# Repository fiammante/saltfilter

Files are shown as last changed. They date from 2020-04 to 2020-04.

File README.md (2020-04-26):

# saltfilter
OpenScad filter for full face snorkeling mask.

Making my full-face protection mask from a snorkel mask. 
Given the lack of masks, after reading [“Universal and reusable virus deactivation system for respiratory protection” article on nature](https://www.nature.com/articles/srep39956) and [“A biomedical engineer created a mask coated in salt that he says could neutralize viruses like the coronavirus in 5 minutes” on business insider](https://www.businessinsider.fr/us/mask-coated-in-salt-neutralizes-viruses-like-coronavirus-2020-2) , then seeing [“European researchers retrofit snorkel masks for coronavirus fight” on Reuters](https://www.reuters.com/article/us-health-coronavirus-czech-snorkel-mask-idUSKBN21H2Z5) I decided to build reusable masks for me and my wife, better than nothing.
I bought a full face mask on amazon and replaced the snorkel by a 3d printed salt filter designed with Openscad https://www.openscad.org/.
This project contains the OpenScad parts for this [masks I bought on Amazon](https://www.amazon.fr/gp/product/B07L8RH96N/ref=ppx_yo_dt_b_asin_title_o04_s00?ie=UTF8&psc=1) 
If you have another mask the inletv.scad out outletv.scad should be changed to fit yours.

The parts to print are filter.scad for the filter itself and grid.scad for the 4 grid separation that maintain the high granularity salt in place.

# Making my full-face protection mask from a snorkel mask.

Given the lack of masks, after reading [&quot;Universal and reusable virus deactivation system for respiratory protection&quot;](https://www.nature.com/articles/srep39956) article on nature and [&quot;A biomedical engineer created a mask coated in salt that he says could neutralize viruses like the coronavirus in 5 minutes&quot;](https://www.businessinsider.fr/us/mask-coated-in-salt-neutralizes-viruses-like-coronavirus-2020-2) on business insider, then seeing [&quot;European researchers retrofit snorkel masks for coronavirus fight&quot;](https://www.reuters.com/article/us-health-coronavirus-czech-snorkel-mask-idUSKBN21H2Z5) on Reuters I decided to build reusable masks for me and my wife, better than nothing.

Here are the steps that I followed

I bought the following &quot;Speedsporting Full Face Snorkel Mask 180°&quot; on Amazon: 

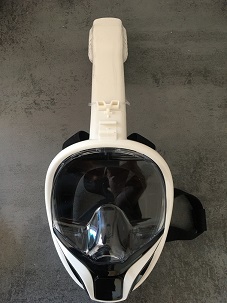
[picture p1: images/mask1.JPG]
Mask1
 

2/ Remove the snorkel one pin to remove) 

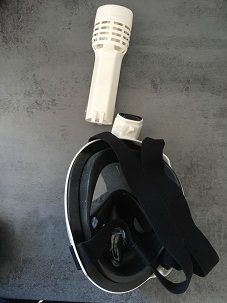
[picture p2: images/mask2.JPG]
Mask2


3/ View from top Air in and out flows. These snorkel masks separate with valves the air flow going in and going out. |

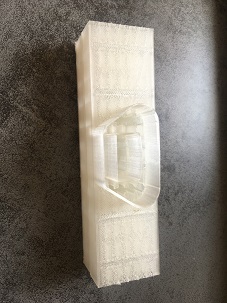
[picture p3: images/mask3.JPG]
Mask3
 |

4/ Created a 3D model of a filter with separated inlet and outlet 

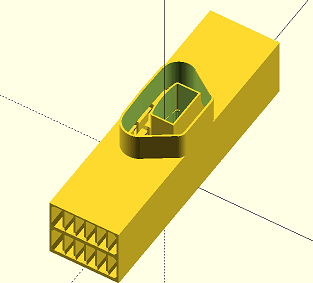
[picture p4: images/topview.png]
Image of Filter top

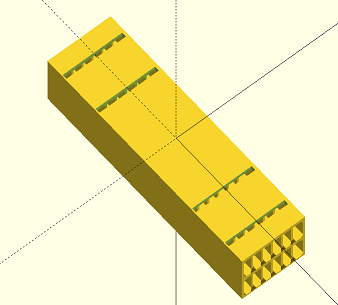
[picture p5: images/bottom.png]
Image of Filter bottom

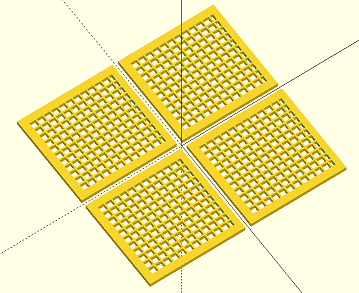
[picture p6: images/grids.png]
Image of Separation grids


5/ After few hours of printing 

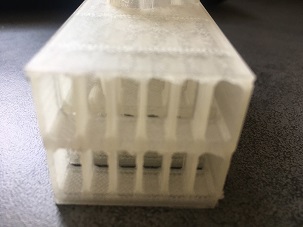
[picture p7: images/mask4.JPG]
Mask4


6/ Side view 

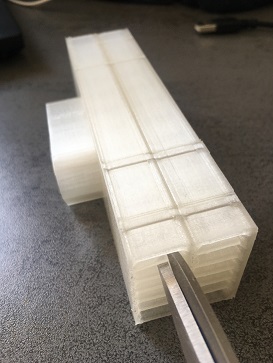
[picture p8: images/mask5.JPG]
Mask5
 |

7/ Insert the inner sliders

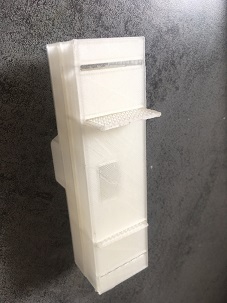
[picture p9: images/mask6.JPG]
Mask6
 

8/ Get dish washer salt, check it is regular salt (Na Cl). The reason being that salt is high grained and will let air flow between the grains. 

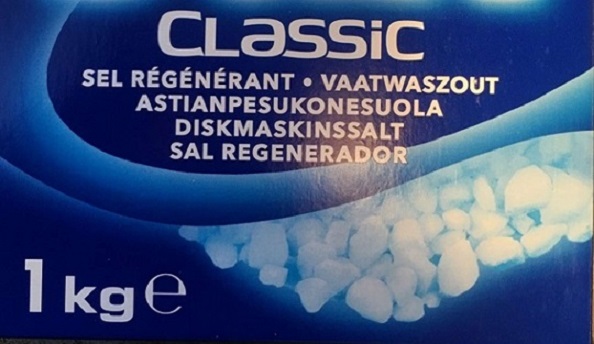
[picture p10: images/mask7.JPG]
Mask7
 |

9/ Cut out the support from the inner sliders to the outside |

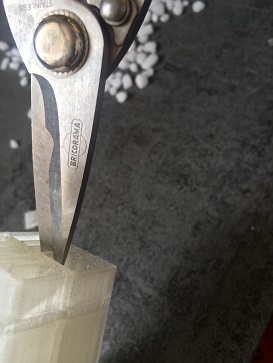
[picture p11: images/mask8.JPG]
Mask8
 |

10/ Side view

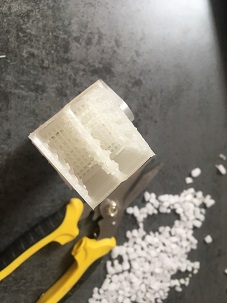
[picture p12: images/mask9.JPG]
Mask9
 

11/ Fill with salt make sure the outer slider can get in. Tamp down to ensure it is full of salt. 

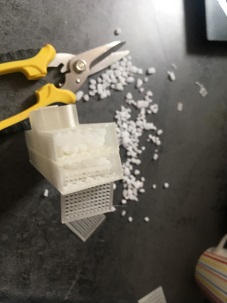
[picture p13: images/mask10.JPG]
Mask10
 

12/ Put the outer slide. Repeat 11 and 12 for the other side.

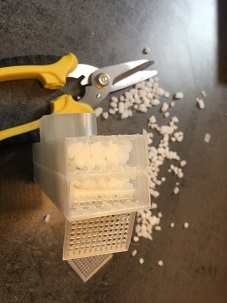
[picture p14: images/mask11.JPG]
Mask11
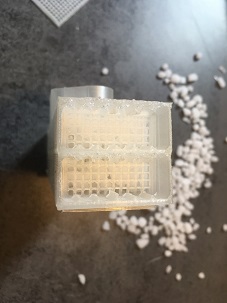
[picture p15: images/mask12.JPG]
Mask12
 

13/ Put the filter in the snorkel place ensure that inlet and outlet are in their respective holes. 

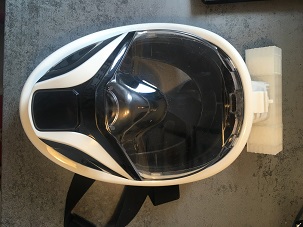
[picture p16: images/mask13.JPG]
Mask13


14/ Inside view. 

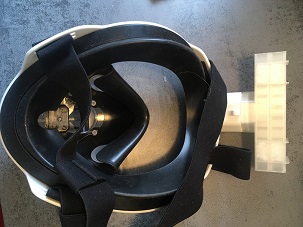
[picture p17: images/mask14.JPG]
Mask14


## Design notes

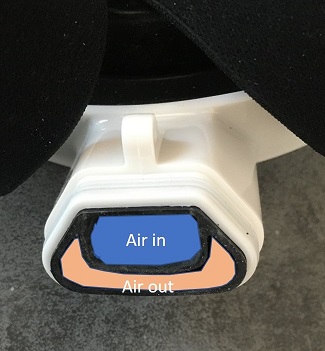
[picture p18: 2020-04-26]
images/air_in_out.jpg

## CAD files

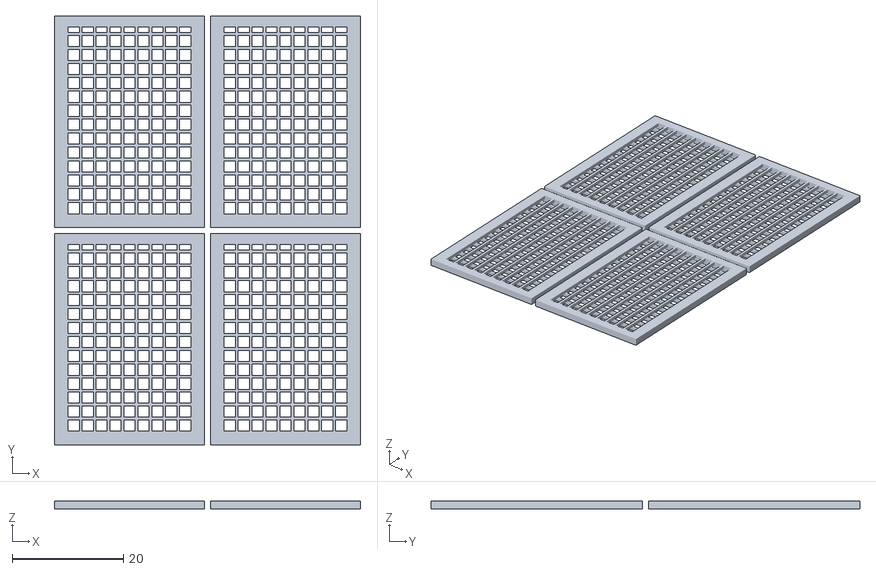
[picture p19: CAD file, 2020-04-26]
stl/grid.stl
55.0 x 77.0 x 1.50

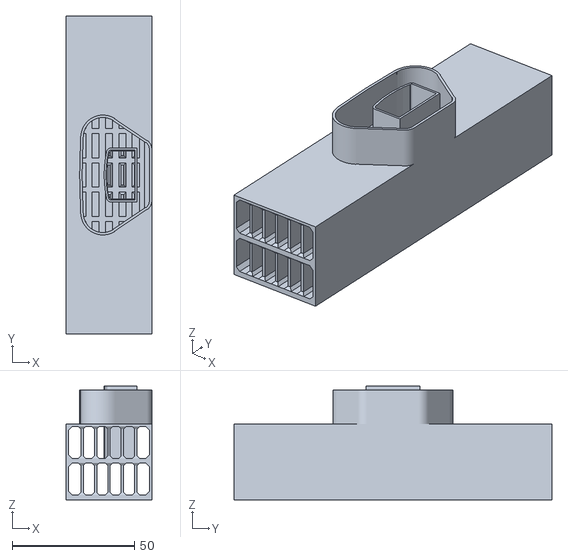
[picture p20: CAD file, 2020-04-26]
stl/filter.stl
35.0 x 130.0 x 46.5

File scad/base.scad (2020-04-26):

include <prism.scad>
include <support.scad>
include <inletv.scad>
module base(w=22, d=12, h=15, th=1,sz=1){
    ch=2;
    union() {
    

  
    translate([-w/2,d/2-th,th]) {cube([w,th,h],center=false);
        translate([0,-ch,0.9*th])prism(w,ch,ch);
        translate([0,-ch,h]) prism(w,ch,-ch);}
    mirror([0,1,0]) {
        translate([-w/2,d/2-th,th]) {cube([w,th,h],center=false);
        translate([0,-ch,0.9*th])prism(w,ch,ch);
        translate([0,-ch,h]) prism(w,ch,-ch);}
    }
    translate([-w/2,-d/2,th/2]) cube([w,d,2*th],center=false);
    translate([0,0,2]) support(w,d-2*(ch+th/2),h-3*th/2,th,4);
}
    
}

//base(120, 35, 15, 1,1);

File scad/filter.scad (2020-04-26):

include <base.scad>
include <inlet.scad>
include <outletv.scad>
module filter(){
    th=1;
    d=35;
    h=15;
    w=130;
    offset=6;
    //translate([0,-d/2,2*h+5*th])cube([2*th,d,4*th],center=false);
    rotate([0,0,90]) difference() {

        difference() {
            union() {
                base(w,d,h,th,1);
            translate([0,0,h]) base(w,d,h,th,1);
                translate([0,-(d/2)+offset,2*th+h]) 
        inletv(2*h);
        translate([0,0,2*h+th/2]) outletv(w,35,h);
            }
            translate([0,-(d/2)+offset+.8,4*th]) hull() scale([0.9,0.87,h]) inletv(2*h);
        }
        

    sh=1.5;
    slh=2*h+4*th;
    sld=d-2*th;
    first=8;
        second=30;
    translate([w/2-4*th-first,-d/2+sh,-3*th])
                cube([2.5*th,sld,slh],center=false);
    mirror([1,0,0]) translate([w/2-4*th-first,-d/2+sh,-3*th])
                cube([2.5*th,sld,slh],center=false);
    translate([w/2-4*th-second,-d/2+sh,-3*th])
                cube([2.5*th,sld,slh],center=false);
    mirror([1,0,0])  translate([w/2-4*th-second,-d/2+sh,-3*th])
                cube([2.5*th,sld,slh],center=false);
//translate([-w,-d,0])cube([2*w,2*d,2*h+5*th],center=false);
}}
filter();

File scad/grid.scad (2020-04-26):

module grid(

//------------parameters---------------------------
// overall size of X dimension
gridX=62,  
// overall size of Y dimension
gridY=60,  
// X border size
borderX=2, 
// Y border size
borderY=2, 
// width of solid part of grid
meshSolid=0.5,
// width of blank part of grid 
meshSpace=2,  
// thickness in Z direction
thickness=1,

// If you want it round, set to "true". For rectangular to "false". If "true" is set, then only gridX and borderX are used as diameters and gridY and borderY are simply ignored
flag_round=false
){

//-------------------------------------------------
meshX=gridX-(borderX*2);
meshY=gridY-(borderY*2);
nX=meshX/(meshSolid+meshSpace);
nY=meshY/(meshSolid+meshSpace);

// Generate mesh as module
module myMesh(){
    for (i=[0:nX]) {
         translate([-(meshX/2)+i*(meshSolid+meshSpace),-meshY/2,]){
             cube(size=[meshSolid,meshY,thickness/2],center=false);
         };
    }

    for (i=[0:nY]) {
        translate([-meshX/2,-(meshY/2)+i*(meshSolid+meshSpace),-thickness/2]){
           cube(size=[meshX,meshSolid,thickness/2],center=false);
        };

    }
}

if (flag_round==true) {
    
    // Genrate frame (Round)
    inner_radius = (gridX-2*borderX)/2;
    difference() {
        cylinder(r=gridX/2, h=thickness, center=true);
        translate([0,0,-0.1]) {
            cylinder(r=inner_radius, h=thickness+0.2, center=true);
        };
    }

    intersection() {
        cylinder(r=inner_radius,h=thickness, center=true);
        myMesh();
    };
    
} else {
    
    // Generate frame (rectancular)
    difference() {
        cube (size=[gridX,gridY,thickness],center=true);
        translate([0,0,-0.1]) {
            cube (size=[meshX,meshY,thickness+0.5],center=true);
        }
    }
    myMesh();
}
}
d=35;
h=15;
w=130;
offset=6;
th=1;
sh=1.5;
slh=2*h+8*th;
sld=d-8*th;
first=8;
translate([(sld+th)/2,(slh+th)/2,0]) 
grid(sld,slh,2,2,0.5,2,1.5*th);
translate([-(sld+th)/2,(slh+th)/2,0]) 
grid(sld,slh,2,2,0.5,2,1.5*th);
translate([(sld+th)/2,-(slh+th)/2,0]) 
grid(sld,slh,2,2,0.5,2,1.5*th);
translate([-(sld+th)/2,-(slh+th)/2,0]) 
grid(sld,slh,2,2,0.5,2,1.5*th);

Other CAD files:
scad/inletv.scad
scad/mesh.scad
scad/outletv.scad
scad/pie.scad
scad/prism.scad
scad/support.scad
scad/tpyramid.scad

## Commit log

2020-04-26 Create initial version
    Create
    [base.scad, filter.scad, grid.scad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]
2020-04-26 Add STL files
    [filter.stl, grid.stl]
2020-04-26 Fix grid width & height
    [grid.scad, grid.stl]
2020-04-26 Better printing grid
    [grid.scad, grid.stl]
2020-04-26 added missing prism
    [prism.scad]
